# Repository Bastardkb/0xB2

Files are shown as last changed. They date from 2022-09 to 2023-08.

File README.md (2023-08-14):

# 0xB2 - splinky
Pro-Micro/Elite-C replacement with USB-C and RP2040.

Designed for use in custom mechanical (split) keyboards, but many other uses are possible.

Splinky v2 Splinvy v1

**This is a fork from the [0xb2 - splinky](https://github.com/plut0nium/0xB2) by plut0nium.**
**It uses a different usb-C port, which is similar to the one of the elite-C and will fit in the Bastardkb case designs.**

## Features:

 * Pro-micro / Sparkfun RP2040 compatible footprint, with 5 extra pins at bottom (Elite-C style)
 * Raspberry Pi RP2040 MCU
 * Up to 16MB flash memory _(depending on component selection and availability)_
 * User LED & USB VBUS detect
 * Low profile USB-C mid-mount connector
 * Designed to be manufactured and assembled by all common PCBA services (including JLCPCB)

<!--![Splinky v2](pcb/doc/render_v2.png?raw=true "Splinky v2 Render")-->

## Pinout

The pinout is compatible with the widely available [SparkFun RP2040](https://www.sparkfun.com/products/18288), with extra GPIO12..16 pins broken out on the lower side.

USB VBUS detection on GPIO19.

> This pinout is a _de facto_ standard, established by actors of the MK community (see discussions in `#RP2040` on the bastardkb Discord server) 

Additionnaly, a user LED is tied to GPIO17, can be used for UF2 bootloader status indication, or any other purpose (or turned OFF, no annoying always-on power LED).

## Programming

The splinky uses a basic two-button reset circuitry.

In order to put the board in bootloader mode, press briefly the RESET button (marked **R**) while holding the BOOT button (the second one).
If the buttons are not reachable (soldered upside down), the /RST pad can be shorted to GND, while the two smaller BOOT pads (next to D8) are maintained shorted (v2 only).

## Manufacturing

Releases contain required information (gerbers, bom, pos) for assembly by JLCPCB.

## Releases

 * **v3** updated pinout - current release
 * **v2** first public release
 * **v1** first prototyping run

## Credits

 * Raspberry Pi Foundation
   * [RP2040 Datasheet](https://datasheets.raspberrypi.com/rp2040/rp2040-datasheet.pdf)
   * [Hardware design with RP2040](https://datasheets.raspberrypi.com/rp2040/hardware-design-with-rp2040.pdf)
 * [SparkFun Pro Micro - RP2040](https://www.sparkfun.com/products/18288)
 * [Adafruit kb2040](https://learn.adafruit.com/adafruit-kb2040)
 * [sea-picro](https://github.com/joshajohnson/sea-picro) - _similar project, I borrowed some cheaper component references ^^_
 * ...

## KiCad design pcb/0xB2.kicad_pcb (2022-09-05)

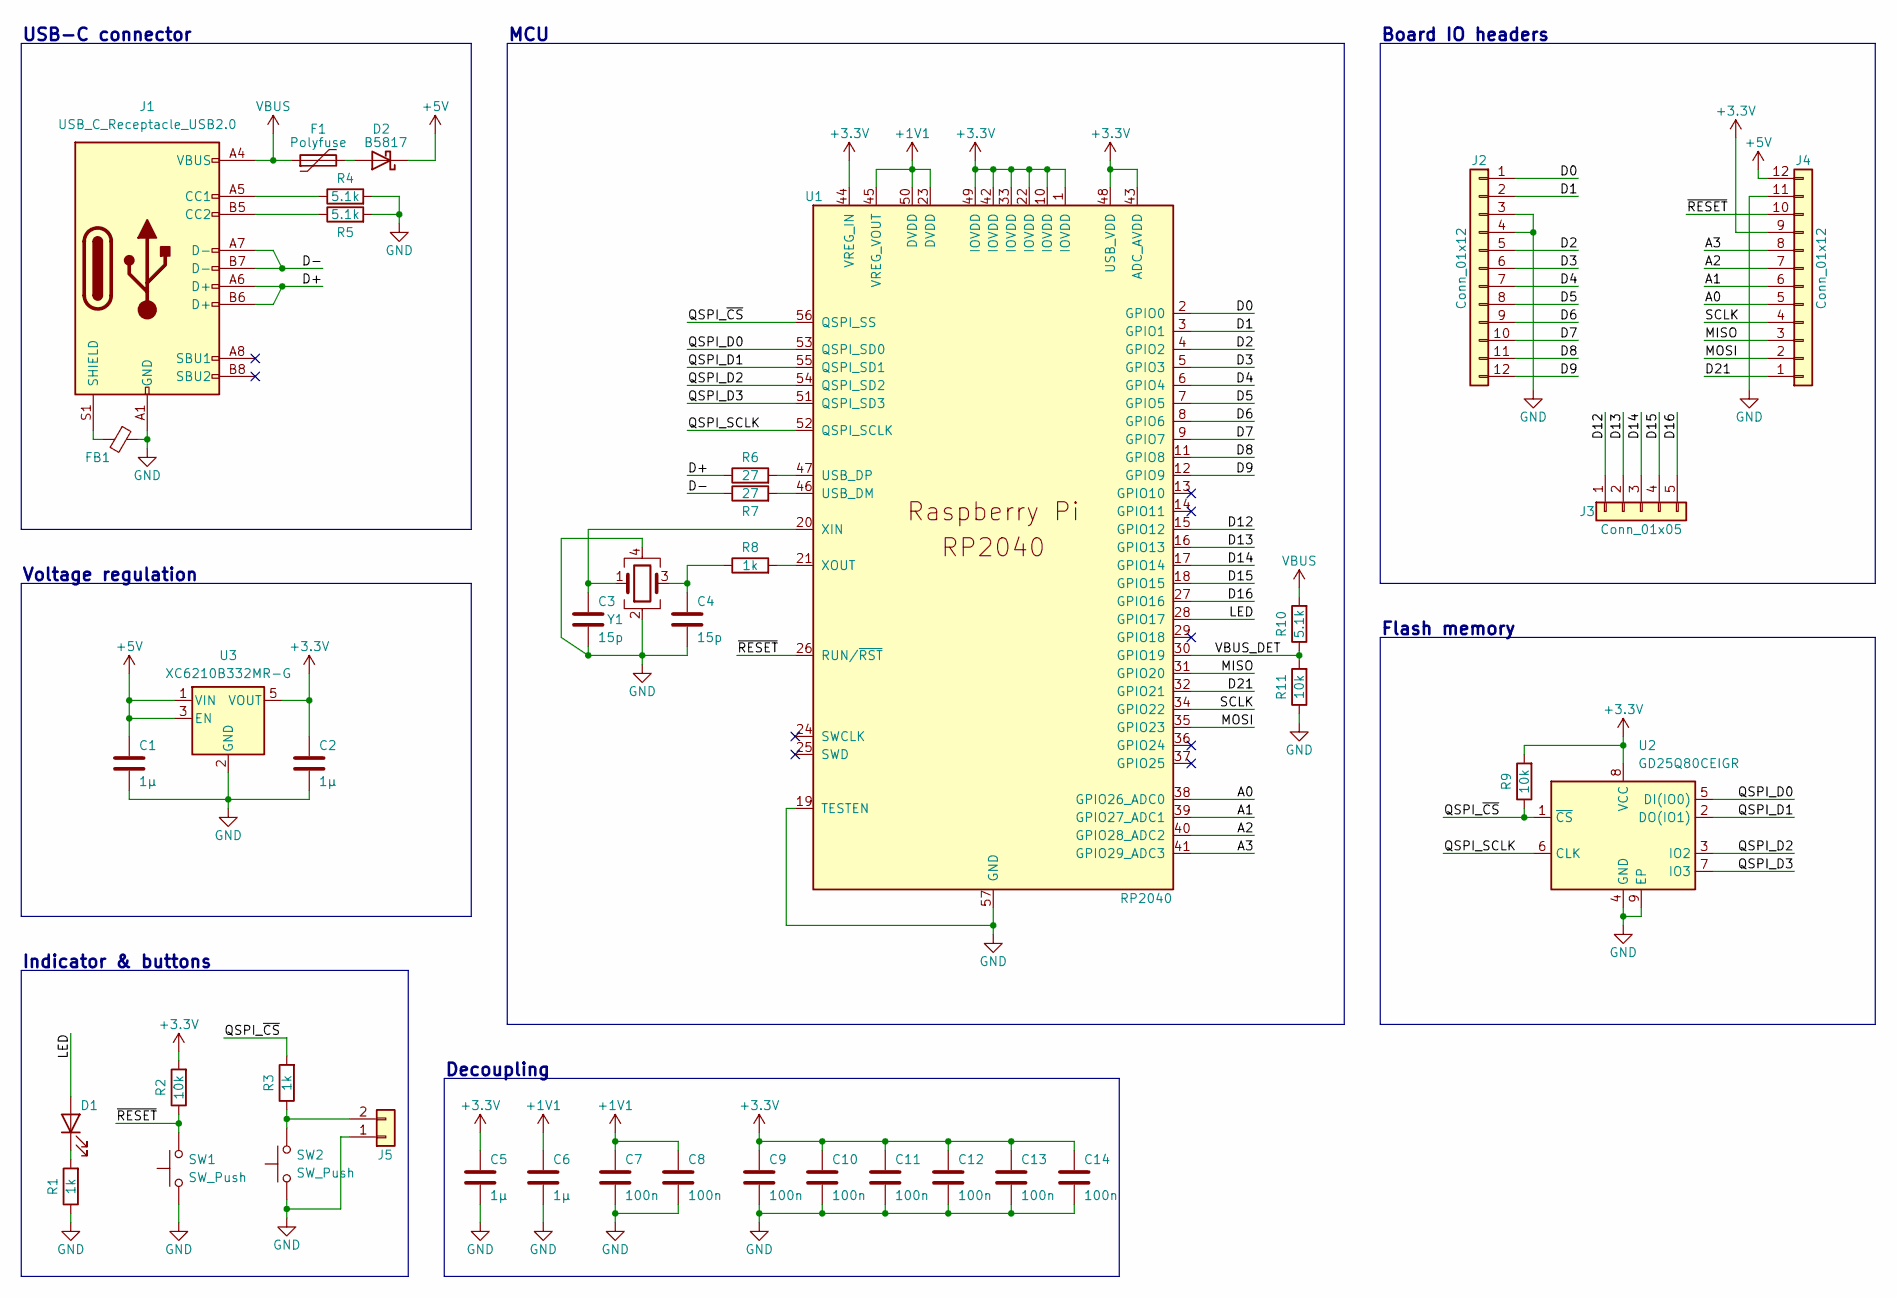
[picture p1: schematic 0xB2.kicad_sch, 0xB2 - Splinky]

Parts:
C1, C2: 1µ; C_0603_1608Metric; LCSC C19666
C3, C4: 15p; C_0402_1005Metric; LCSC C1548
C5, C6: 1µ; C_0402_1005Metric; LCSC C52923
C7, C8, C9, C10, C11, C12, C13, C14: 100n; C_0402_1005Metric; LCSC C1525
D1: LED; LED_0402_1005Metric; LCSC C130719
D2: B5817; D_SOD-323; LCSC C123899
F1: Polyfuse; Fuse_0603_1608Metric; LCSC C69679
FB1: FerriteBead_Small; L_0603_1608Metric; LCSC C98288
J1: USB_C_Receptacle_USB2.0; USB_C_Receptacle_HRO_TYPE-C-31-M-14; LCSC C223907
J2, J4: Conn_01x12; PinHeader_1x12_P2.54mm
J3: Conn_01x05; PinHeader_1x05_P2.54mm
J5: Conn_01x02; PinHeader_1x02_P1.27mm_Vertical
R1, R3, R8: 1k; R_0402_1005Metric; LCSC C11702
R2, R9, R11: 10k; R_0402_1005Metric; LCSC C25744
R4, R5, R10: 5.1k; R_0402_1005Metric; LCSC C25905
R6, R7: 27; R_0402_1005Metric; LCSC C25100
SW1, SW2: SW_Push; SW_SPST_CK_KXT3; LCSC C319433
U1: RP2040; QFN-56-1EP_7x7mm_P0.4mm_EP3.2x3.2mm; LCSC C2040
U2: GD25Q80CEIGR; USON-8-1EP_3x2mm_P0.5mm_EP0.25x1.65mm; LCSC C395484
U3: XC6210B332MR-G; SOT-23-5; LCSC C82942
Y1: Crystal_GND24; Crystal_SMD_2520-4Pin_2.5x2.0mm; LCSC C2149204

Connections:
+1V1: C6.1, C7.1, C8.1, U1.23 (DVDD), U1.45 (VREG_VOUT), U1.50 (DVDD)
+3V3: C2.1, C5.1, C9.1, C10.1, C11.1, C12.1, C13.1, C14.1, J4.9, R2.2, R9.2, U1.1 (IOVDD), U1.10 (IOVDD), U1.22 (IOVDD), U1.33 (IOVDD), U1.42 (IOVDD), U1.43 (ADC_AVDD), U1.44 (VREG_IN), U1.48 (USB_VDD), U1.49 (IOVDD), U2.8 (VCC), U3.5 (VOUT)
+5V: C1.1, D2.1 (K), J4.12, U3.1 (VIN), U3.3 (EN)
/A0: J4.5, U1.38 (GPIO26_ADC0)
/A1: J4.6, U1.39 (GPIO27_ADC1)
/A2: J4.7, U1.40 (GPIO28_ADC2)
/A3: J4.8, U1.41 (GPIO29_ADC3)
/D0: J2.1, U1.2 (GPIO0)
/D1: J2.2, U1.3 (GPIO1)
/D2: J2.5, U1.4 (GPIO2)
/D3: J2.6, U1.5 (GPIO3)
/D4: J2.7, U1.6 (GPIO4)
/D5: J2.8, U1.7 (GPIO5)
/D6: J2.9, U1.8 (GPIO6)
/D7: J2.10, U1.9 (GPIO7)
/D8: J2.11, U1.11 (GPIO8)
/D9: J2.12, U1.12 (GPIO9)
/D12: J3.1, U1.15 (GPIO12)
/D13: J3.2, U1.16 (GPIO13)
/D14: J3.3, U1.17 (GPIO14)
/D15: J3.4, U1.18 (GPIO15)
/D16: J3.5, U1.27 (GPIO16)
/D21: J4.1, U1.32 (GPIO21)
/D+: J1.A6 (D+), J1.B6 (D+), R6.1
/D-: J1.A7 (D-), J1.B7 (D-), R7.1
/LED: D1.2 (A), U1.28 (GPIO17)
/MISO: J4.3, U1.31 (GPIO20)
/MOSI: J4.2, U1.35 (GPIO23)
/QSPI_D0: U1.53 (QSPI_SD0), U2.5 (DI(IO0))
/QSPI_D1: U1.55 (QSPI_SD1), U2.2 (DO(IO1))
/QSPI_D2: U1.54 (QSPI_SD2), U2.3 (IO2)
/QSPI_D3: U1.51 (QSPI_SD3), U2.7 (IO3)
/QSPI_SCLK: U1.52 (QSPI_SCLK), U2.6 (CLK)
/QSPI_~CS: R3.2, R9.1, U1.56 (QSPI_SS), U2.1 (~CS)
/SCLK: J4.4, U1.34 (GPIO22)
/VBUS_DET: R10.1, R11.2, U1.30 (GPIO19)
/~RESET: J4.10, R2.1, SW1.2, U1.26 (RUN/~RST)
GND: C1.2, C2.2, C3.2, C4.2, C5.2, C6.2, C7.2, C8.2, C9.2, C10.2, C11.2, C12.2, C13.2, C14.2, FB1.1, J1.A1 (GND), J1.A12 (GND), J1.B1 (GND), J1.B12 (GND), J2.3, J2.4, J4.11, J5.1, R1.1, R4.2, R5.2, R11.1, SW1.1, SW2.1, U1.19 (TESTEN), U1.57 (GND), U2.4 (GND), U2.9 (EP), U3.2 (GND), Y1.2, Y1.4
unnamed: C3.1, U1.20 (XIN), Y1.1
unnamed: C4.1, R8.1, Y1.3
unnamed: D1.1 (K), R1.2
unnamed: D2.2 (A), F1.2
unnamed: FB1.2, J1.S1 (SHIELD)
unnamed: J1.A5 (CC1), R4.1
unnamed: J1.B5 (CC2), R5.1
unnamed: J5.2, R3.1, SW2.2
unnamed: R6.2, U1.47 (USB_DP)
unnamed: R7.2, U1.46 (USB_DM)
unnamed: R8.2, U1.21 (XOUT)
VBUS: F1.1, J1.A4 (VBUS), J1.A9 (VBUS), J1.B4 (VBUS), J1.B9 (VBUS), R10.2

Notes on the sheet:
Decoupling
Board IO headers
USB-C connector
Indicator & buttons
Voltage regulation
MCU
Flash memory

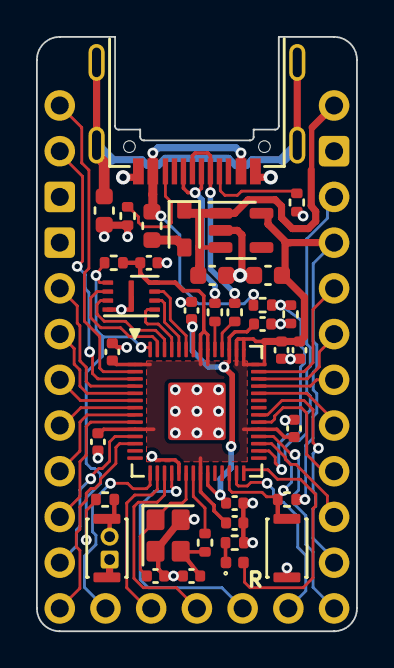
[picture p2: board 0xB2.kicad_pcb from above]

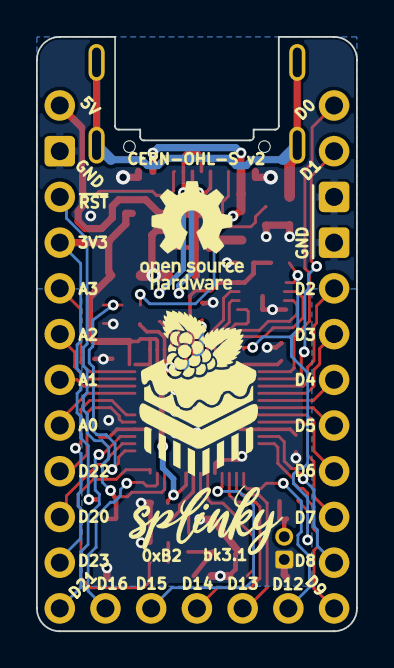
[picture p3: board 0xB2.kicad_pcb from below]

Board: 2 copper layers, 17.8 x 33.0 mm, 42 parts (2 on the bottom side), 50 nets.

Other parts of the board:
rb_cake: G*****; rb_cake
splinky: G*****; splinky

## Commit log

2022-05-18 import libs
    [0xB2.kicad_pcb, 0xB2.kicad_sch]
2022-05-18 add new and remove old connectors
    [0xB2.kicad_pcb, 0xB2.kicad_sch]
2022-05-18 add reversible reset button
    [0xB2.kicad_pcb, 0xB2.kicad_sch]
2022-05-18 remove small reset button
    [0xB2.kicad_pcb, 0xB2.kicad_sch]
2022-05-18 square gnd connectors
    [0xB2.kicad_pcb]
2022-05-18 daughterboard work
    [0xB2.kicad_pcb, 0xB2.kicad_sch]
2022-05-18 separate file for daughterboards
    [daughterboard.kicad_pcb, daughterboard.kicad_sch]
2022-05-19 silkscreen. routing
    [daughterboard.kicad_pcb]
2022-05-23 switch to C167321 for usb-c
    [daughterboard.kicad_sch]
2022-05-23 route daughterboards
    [0xB2.kicad_pcb, daughterboard.kicad_pcb]
2022-05-23 gnd routing
    [daughterboard.kicad_pcb]
2022-05-23 move daughterboard to its own repo
    [0xB2.kicad_pcb, 0xB2.kicad_sch, daughterboard.kicad_pcb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]
2022-05-25 jlc parts
    [0xB2.kicad_pcb]
2022-06-08 same layout as chris (need to route)
    [0xB2.kicad_pcb, 0xB2.kicad_sch]
2022-09-05 revert to 3.0
    [0xB2.kicad_pcb, 0xB2.kicad_sch]

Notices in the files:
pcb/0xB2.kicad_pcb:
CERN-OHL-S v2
